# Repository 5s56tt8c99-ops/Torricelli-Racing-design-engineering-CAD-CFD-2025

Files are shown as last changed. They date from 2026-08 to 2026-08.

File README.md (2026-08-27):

# Torricelli-Racing-design-engineering-CAD-CFD-
This project shows the creation and CFD analysis of a formula 1 in schools car that took part at the triveneto regional finals of 2025.
The triveneto stage was a second event we took place after passing the preliminary stage. Here I show the differences between the two cars and the file of the second and more competitive one. The software used are Autodesk CFD and Autodesk Fusion.

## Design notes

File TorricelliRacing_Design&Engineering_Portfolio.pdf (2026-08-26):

# tORRICELLI

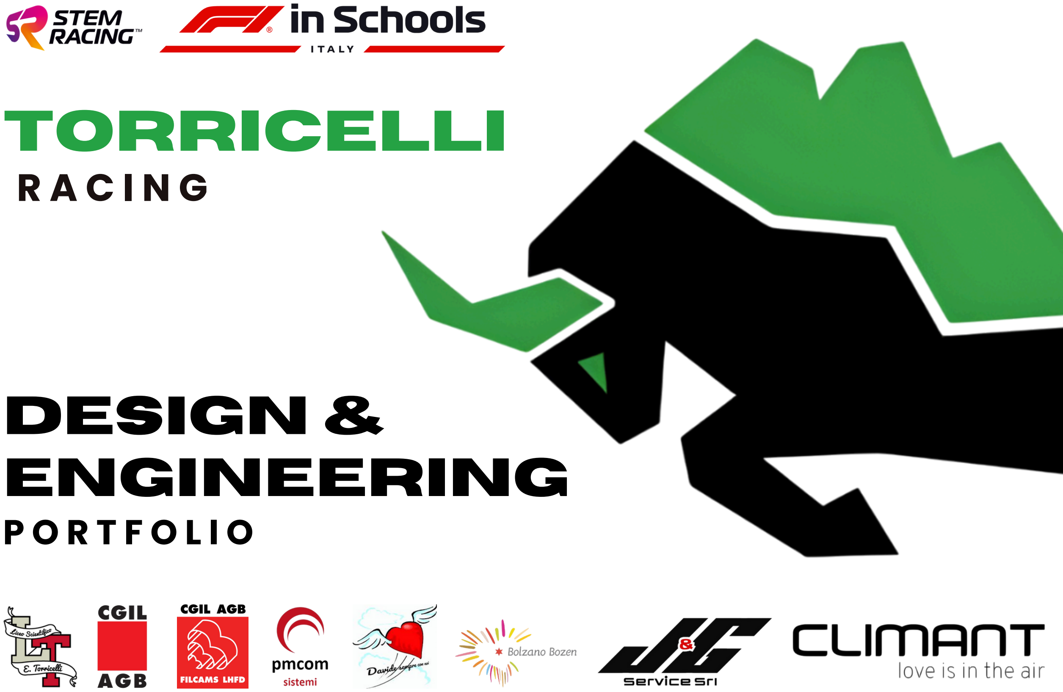
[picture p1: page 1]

# engineering

# P O R T F O L I O

# design &

# R A C I N G

# QUALIFIERS’ CAR ANALYSIS

After completing the regional qualifiers, we carefully analyzed the performance of our car. Although it showcased some good aerodynamic ideas — like airfoil-shaped wings and airflow management devices — several weaknesses were identified, highlighting the need for a major redesign.

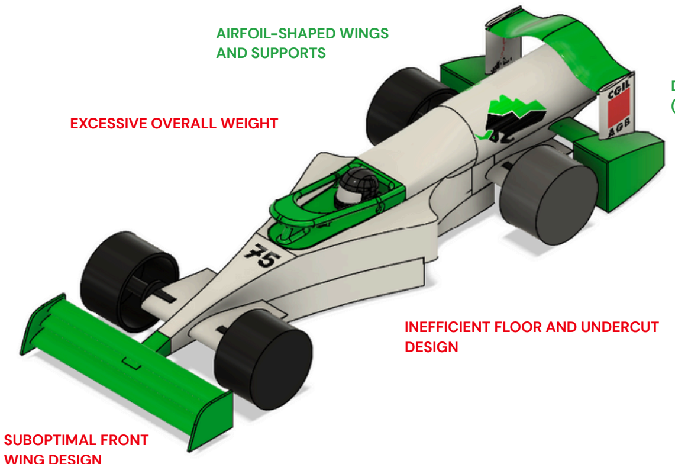
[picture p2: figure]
AIRFOIL-SHAPED WINGS AND SUPPORTS; SUBOPTIMAL FRONT; EXCESSIVE OVERALL WEIGHT; INEFFICIENT FLOOR AND UNDERCUT DESIGN

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
# MAIN GOALS

Based on this analysis, we decided to completely redesign the car while retaining some successful concepts. Our main goals were:
Reducing the weight down to the minimum limit by redimensioning some shapes (like minimizing the length of the chamber) and changing materials to some better performant ones
Redesigning the front wing for improved airflow management and reduced drag and removing unneccessary parts
Optimizing the floor and undercut for a cleaner and faster air passage
Introducing bearing-based wheel assemblies to minimize friction and rotational resistance
The regulatory updates allowed us to innovate further, particularly in the wheel and support structure design, pushing us to rethink every element with performance optimization in mind.

DECENT AERODYNAMIC CONCEPTS (E.G., AIRFLOW CLEANERS)

WING DESIGN

## QUALIFIERS’ CAR

## REGIONAL FINALS’ CAR

VS

EXPLANATION: STRENGTHS / WEAKNESSES

# KEY DESIGN OBJECTIVES

At the start of the redesign phase, we set two main design priorities: maximizing underbody airflow (big undercut) and minimizing the car’s frontal surface area (narrow wheel axis width). These choices aimed to reduce aerodynamic drag while maintaining stability and regulatory compliance.

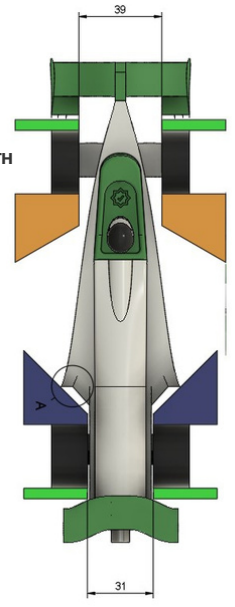
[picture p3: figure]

Key Objectives
Big undercut: create the largest possible free airflow path under the car to reduce ground friction and air turbulence and maximise free flow.
Minimal width: design a narrow wheel axis width and small wheels to lower drag and minimize frontal area.
New front wing: redirect airflow efficiently around the front wheels without blocking the underbody airflow.
Lightweight components: replace or redesign heavy parts to achieve minimum weight.
Simple and small rear wing: keep the rear wing lightweight and aerodynamically clean to avoid unnecessary drag

# SKETCHING PHASE

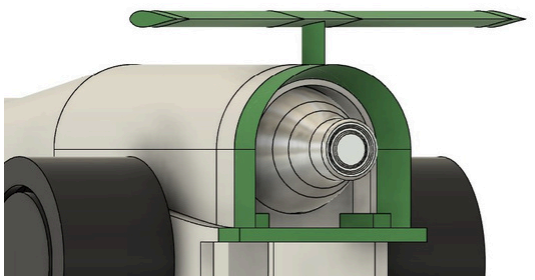
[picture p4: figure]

In the early sketching stage, we explored two possible layouts for the Virtual Cargo (mandatory volume):
Virtual Cargo placed under the Halo
Virtual Cargo placed behind the Halo
We chose the second option as it allowed a higher and more continuous undercut, better supporting our key aerodynamic concept.
Further design decisions — such as the placement of sidepods, deflectors and halo connections — were all influenced by our goal to maintain a clean, unrestricted airflow underneath the car.

MINIMAL WIDTH

SMALL AND SIMPLE REAR WING

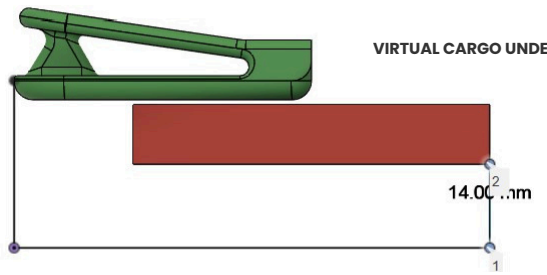
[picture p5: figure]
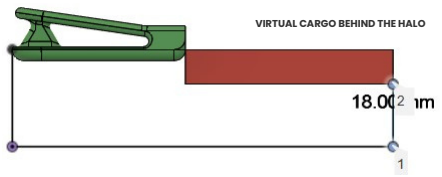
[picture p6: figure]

VIRTUAL CARGO BEHIND THE HALO | VIRTUAL CARGO UNDER THE HALO

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
Redesign Motivation
The front wing used in the qualifiers was aerodynamically inefficient and heavy. To improve performance, we chose to completely redesign the wing, focusing on drag reduction, regulatory compliance and structural simplicity.

Design Choices and Features
A single-vane wing was selected for simplicity and reduced frontal impact with air.
It is attached to a short, thin nose cone, minimizing drag and maximizing clean airflow.
Endplates were placed in front of the wheels, designed to redirect air both around and over them, while complying with rule T8.7.
The first version of the endplates was too heavy and forced an excessively narrow wing. We redesigned them to be slimmer and more effective.
The wing is mounted high above the ground to eliminate the need for extra connectors (which would increase drag) and is slightly bent downwards to meet rule T8.5.2.
A neutral airfoil shape was used, avoiding both lift and downforce to maintain clean airflow.

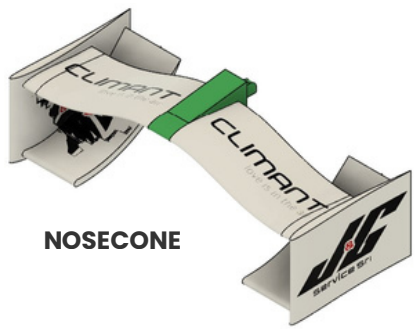
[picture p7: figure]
NOSECONE

Manufacturing and Assembly
The entire wing and nose assembly is printed as a single piece, ensuring precision and reducing weight. A custom mounting point was designed to connect the front wing directly to the car body, offering rigidity with minimal aerodynamic disruption.

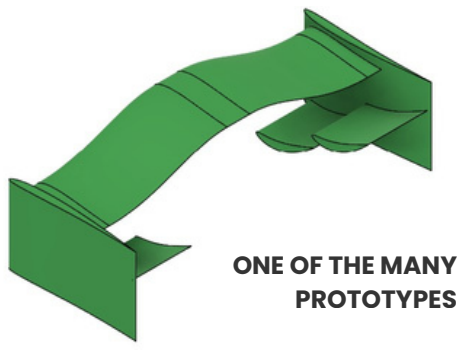
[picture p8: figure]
ONE OF THE MANY PROTOTYPES

Performance Improvement
Compared to the first version, our final design showed a 19% reduction in drag based on CFD analysis — confirming the aerodynamic benefits of our approach.

# FRONT WING & SUPPORT DEVELOPMENT

To address the aerodynamic issues of the initial designs, we tested over ten different front wing specifications — many with small adjustments, but a few with major conceptual changes.
We first modified the angle of the endplate’s airfoil, making it less steep. CFD results improved slightly, but the problem wasn’t fully solved.
Next, we tested a double-vane endplate, which reduced drag further, but still didn’t meet our expectations.
Finally, we created a more unconventional solution: we added cambered airfoils underneath the endplates to redirect air sideways. This approach showed a significant improvement in drag reduction and was integrated into the final design.
Each version was simulated using Autodesk CFD and evaluated with visual flow maps and pressure values.

# DEVELOPMENT ITERATIONS & CFD TESTING

FEATURE | FINAL DESIGN
WING TYPE | SINGLE VANE
AIRFOIL PROFILE | NEUTRAL
ENDPLATE POSITIONING | FRONT OF WHEELS
NOSE CONE | THIN AND SHORT
ASSEMBLY | PRINTED AS SINGLE BLOCK
DRAG REDUCTION (CFD) | ~19% VS. FIRST DESIGN
RULE COMPLIANCE | T8.5.2, T8.7

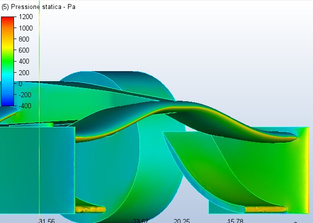
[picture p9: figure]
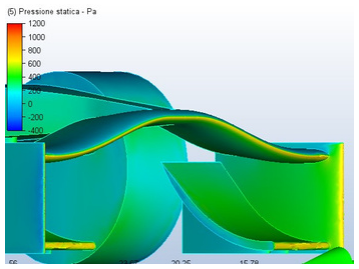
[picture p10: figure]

FIRST PROTOTYPE’S CFD | FINAL PROTOTYPE’S CFD

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
FEATURE | FINAL DESIGN
SUPPORT TYPE | ADD-ON WITH CENTER STRUT
CONNECTION POINT | REAR OF CHAMBER
ASSEMBLY COMPLEXITY | VERY LOW
DRAG IMPACT | SIGNIFICANTLY REDUCED

# REAR WING & MOUNTING SYSTEM

Redesign Motivation
The rear wing from the qualifiers was overly complex and difficult to assemble. Since the rear wing generates little aerodynamic benefit and primarily adds drag, our goal was to simplify it while maintaining stability and aesthetic integration.

Design Evolution
We removed the previous connection system, which attached the wing to rear deflectors, as it was unnecessarily complicated and tested two new mounting solutions:
a. A wing that twists and connects directly to the chamber walls.
A simplified add-on behind the chamber, with a small airfoil-shaped support connecting to the center of the wing.

b.

After comparison, we chose the second design due to its lower surface impact, improved stability, and ease of manufacturing.

Key Features
Compact and clean shape with minimal drag footprint.
Shortened rear section of the car to compensate for the longer wheelbase caused by halo and virtual cargo placement.
Final wing has a curved profile, which better integrates with the car’s structure and makes the wing be compliant with both rule T7.9 and T9.4.1

Outcome
The new rear wing is aerodynamically cleaner, structurally simpler, and much easier to mount — improving both performance and assembly workflow.

TWISTED WING

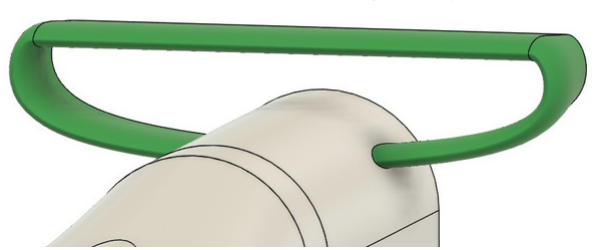
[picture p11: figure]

MOUNTED WING

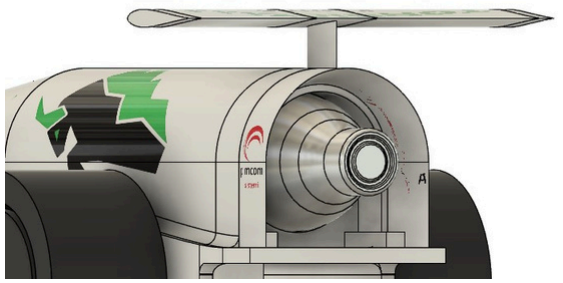
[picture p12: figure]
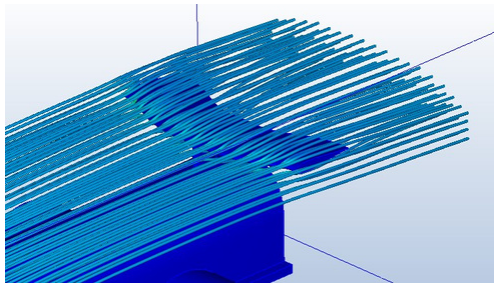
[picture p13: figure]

REAR WING CFD ANALYSIS: CLEAR FLOW WITHOUT | REAR VIEW OF THE REAR WING
TURBOLENCES

FEATURE | DESIGN CHOICE
VIRTUAL CARGO | BEHIND HALO
UNDERCUT SHAPE | CONTINUOUS, WIDE
TUNNEL WALLS | CONSTANT-WIDTH, STRAIGHT
SIDEPODS HEIGHT | 2 MM FROM GROUND
HALO-CHAMBER LINK | TOP: LOFTED / BOTTOM: VERTICAL

# DESIGN OBJECTIVES

One of the key goals in our redesign was to maximize free airflow beneath the car by creating a wide and straight undercut. At the same time, we aimed to minimize turbulence and ensure structural simplicity.

Element Positioning and Initial Decisions:
During the sketching phase, we compared two possible layouts for the Virtual Cargo: below or behind the Halo. We chose the second option as it allowed a taller and more continuous undercut, improving airflow performance while still complying with all regulations.

# UNDERCUT & TUNNEL DEVELOPMENT

The undercut area was redesigned to be wider and more stable than in the qualifiers’ car.
In the previous design, the use of deflectors under the car caused unwanted turbulence. We replaced them with tunnel walls that keep the airflow attached and laminar.
These walls maintain the same width for their entire length to avoid flow separation.
A simple vertical connection links the chamber to the tunnel roof, avoiding unnecessary curves and aiding clean flow.

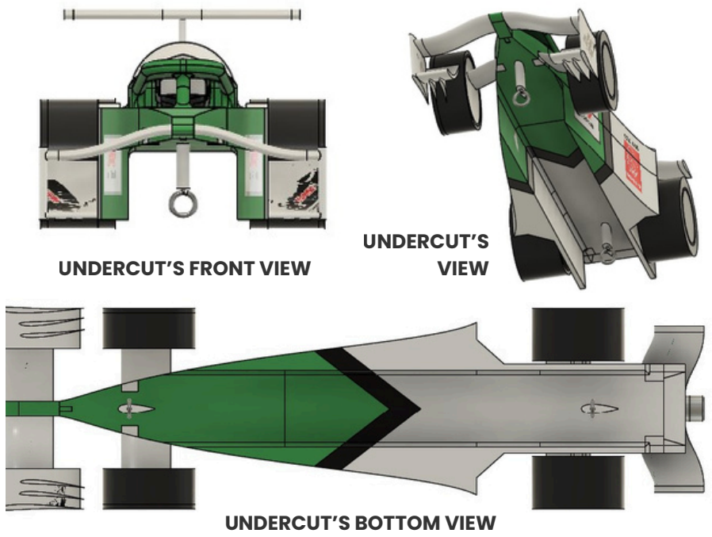
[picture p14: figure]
UNDERCUT’S BOTTOM VIEW; UNDERCUT’S FRONT VIEW; UNDERCUT’S VIEW

# SIDEPODS & HALO-CHAMBER CONNECTION

We added sidepods raised 2 mm off the ground to redirect air around the rear wheels.
The top of the Halo connects to the chamber with a clean lofted transition. A small cylindrical-shaped part was added to the loft in order to clean the turbolences generated by the helmet. The bottom half forms vertical walls connecting directly to the tunnel roof, simplifying geometry and aiding C

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
FINALS’ CAR’S UNDERCUT FLOW: THE FLOW IS STRAIGHT WITHOUT UNWANTED DEVIATIONS

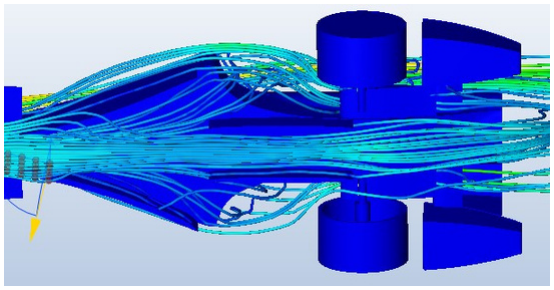
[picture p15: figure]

QUALIFICATIONS’ CAR’S UNDERCUT FLOW: PART OF THE FLOW IS DIVERTED LATERALLY (COANDA EFFECT & VENTURI EFFECT) WHICH

SIDEPOD & HALO-CHAMBER CONNECTION GENERATES UNWANTED TURBOLENCE

W

H

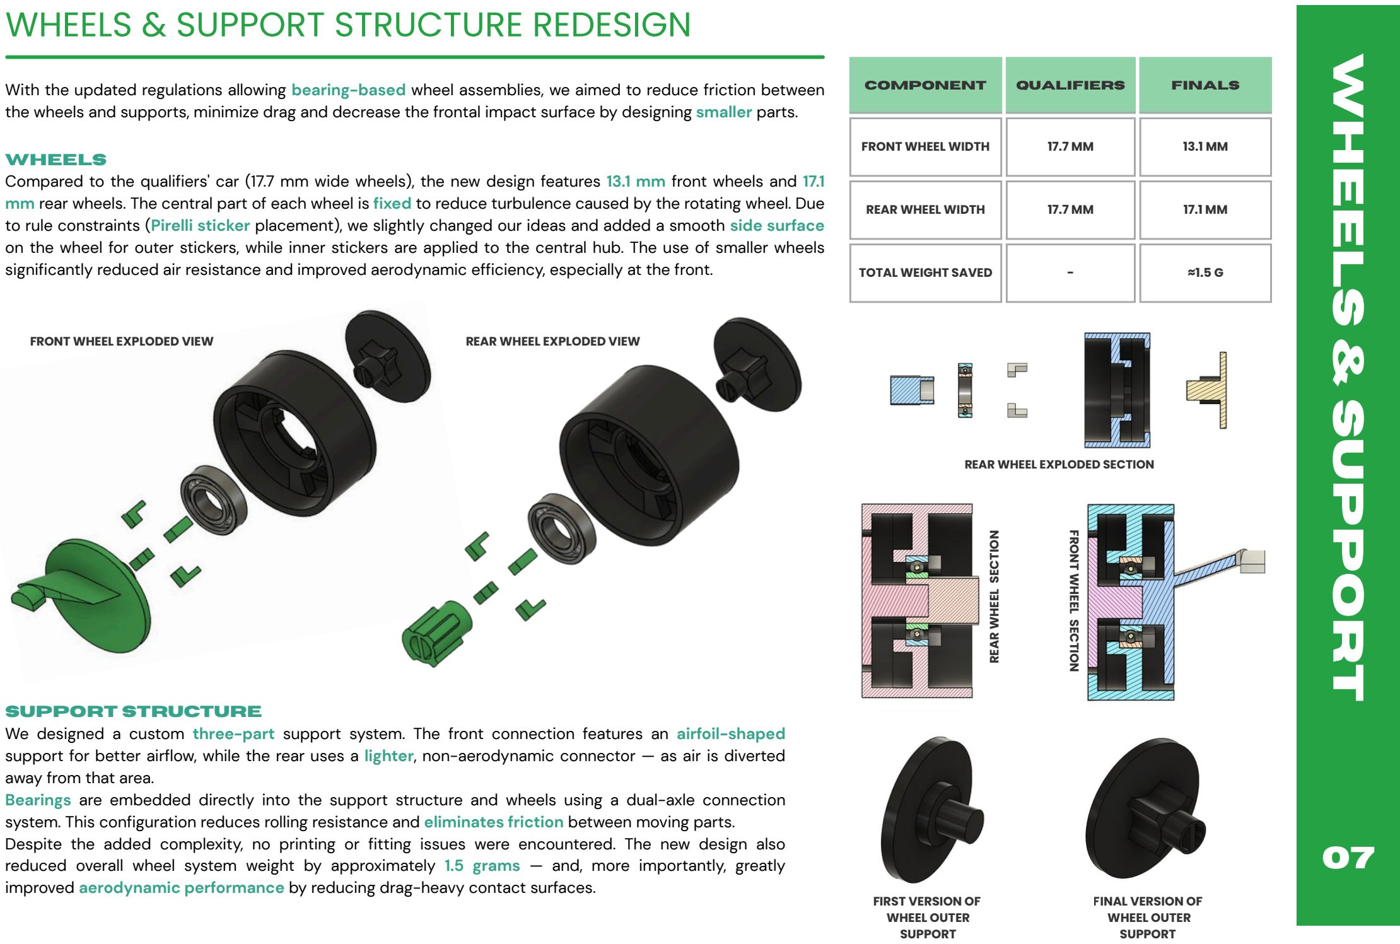
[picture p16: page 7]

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
# THE TEAM WHEELS & SUPPORT 07

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
# SIG

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
allo

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
el a

s

s

e

m

blie

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
minimiz

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
al im

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
alle

r
p

a

r

t

s. Wheels Compared to the qualifiers' car (17.7 mm wide wheels), the new design features 13.1 mm front wheels and

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
els. T

h

e

c

e

n

t

r

al p

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
el is

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
el. D

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
elli

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
slig

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
r id

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
el f

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
hile in

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
plie

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
al h

u

b. T

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
alle

r

w

h

e

els
sig

nific

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
d im

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
ficie

n

c

y,

e

s

p

e

cially

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
t. Support Structure We designed a custom three-part support system. The front connection features an airfoil-

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
hile

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
a li

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
air is

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
a. Bearings are embed
d

e

d

dir

e

c

tly in

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
m. T

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
ollin

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
s. Despite the added complexity, no printing or fitting issues were encountered. The new desig n

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
all w

h

e

el s

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
e im

p

o

r

t

a

n

tly,

g

r

e

a

tly improved aerodynamic performance by reducing drag-heavy contact surfaces. FRONT WHEEL EXPLODED VIEW | REAR WHEEL EXPLODED VIEW | REAR WHEEL EXPLODED SECTION REAR WHEEL SECTION | FRONT WHEEL SECTION

# WEIGHT REDUCTION STRATEGY & FINAL MASS

Initial Challenge
Our first complete design was over 10 grams above the weight limit (qualifiers car: ~95g without CO₂ canister).
Since the F1 in Schools block has low density, we realized that major reductions had to come from 3D-printed components. The bearings (8g total) were non-negotiable, wings were already small, so we could mostly trim the wheels.

Reduction Process
Switched from PLA to Polypropylene (PP) for some components (1.25g/cm³ vs. 0.9g/cm³).
Reduced wheel surface thickness from 2 mm to 1.5 mm.
Replaced the inner connection with a lighter rim-style structure.
Cut excess material from supports and bearing holders using structural optimization.
In order not to increase the weight of the car and for reasons of time, we decided not to paint the car. We put on the stickers: name, logo, number and sponsors (plus the pirelli and f1 stickers in schools that will be given at the regional finals)

FinalWeight Estimate
After design optimization and printing tests, the estimated final mass is ≈50.2g (without stickers).
This is almost 45g lighter than the qualifiers car and just above the minimum allowed.

Performance Rationale
Based on our data from qualifiers, 10g of excess weight cost us approximately 0.1 seconds in race time — making this weight reduction crucial for improving our performance.

HEAVIER WEIGHT

REDUCED WEIGHT

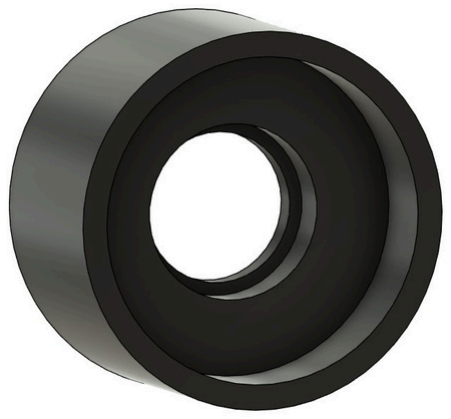
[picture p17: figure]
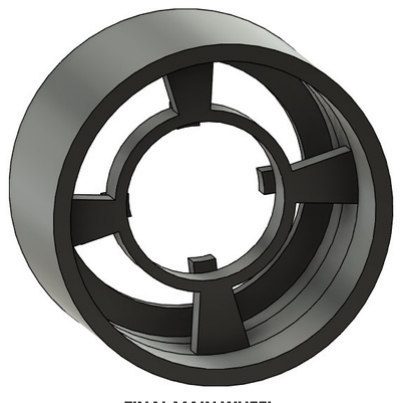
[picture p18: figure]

FIRST DESIGN OF MAIN WHEEL | FIRST WEIGHT REDUCTION | FINAL MAIN WHEEL

WEIGHT REDUCTION:
~3.4G FOR EACH WHEEL (FROM 7G TO 3.6G) AND ~44.84G FOR THE FULL CAR - W/O CAN - (FROM 95G TO 50.16G)

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
# SIS

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
# E IM

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
D. W

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
cially

o

n
vis

u

alizin

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
d id

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
e. More than 10 versions of the front wing alone were tested, together with diff e

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
el w

alls

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
, in

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
ximis

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
e. Key Findings The final front wing reduced drag by ~19% compared to the initial ve

r

sio

n. Positioning the Virtual Cargo behind the Halo significantly improved the u n

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
w. Removing underbody deflectors and replacing them with clean tunnel walls elimina t

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
d in

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
r. CFD Tools Used Traces to observe direction and velocity

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
r in

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
all c

alc

ula

tio

n

s

t

o id

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
al a

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
al q

u

alifie

r

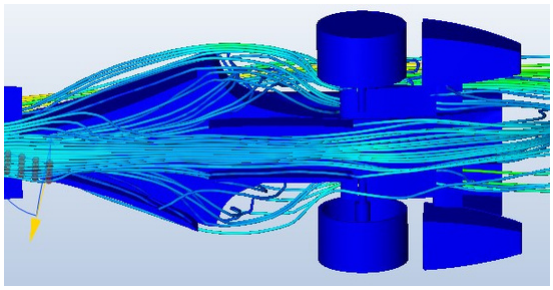
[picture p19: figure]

s' car, with major gains in drag reduction and flow cleanliness. | FINALS’ CAR’S UNDERCUT FLOW:

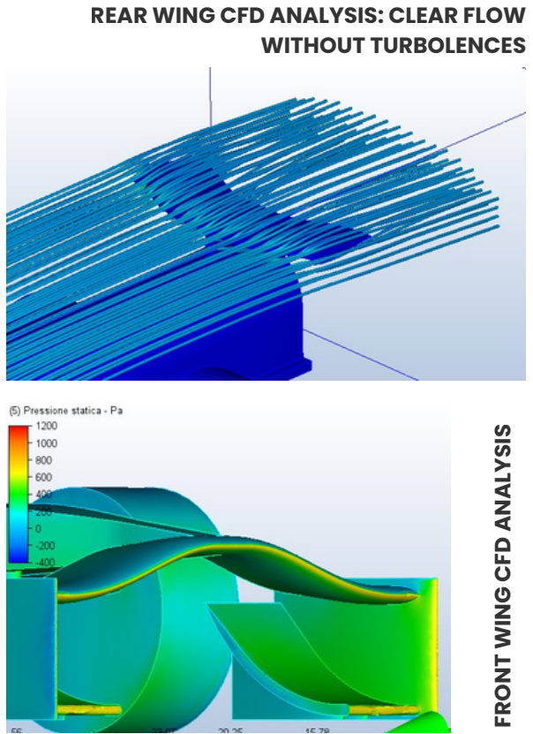
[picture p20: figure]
FRONT WING CFD ANALYSIS RE

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
FINALS’ CAR’S FRONT FLOW QU

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
# THE TEAM CFD & IMPOVEMENTS 09

# MATERIALS AND 3D PRINTING STRATEGY

Material Selection
To reduce weight and maintain structural reliability, we carefully selected materials for each printed component:
PLA (d=1.25 g/cm³) was used for the front and rear wings and for the internal supports, due to its rigidity and easier printing with support materials.
Polypropylene (PP) (d=0.9 g/cm³) was chosen for the remaining components because of its lower density.
However, PP is more flexible and difficult to print accurately. Some parts showed small surface irregularities, which we managed by simplifying geometries and avoiding too-thin features.

Printing Process
All parts were printed using FDM 3D printers, at BITZ FabLab (unibz): we used a Ultimaker S3 dual extrusion and a Prusa XL
Water-soluble support structures were used with PLA prints to allow more complex shapes and cleaner results.
Each component was printed at least once for testing before final assembly. As of April 29, most parts had already been approved, except for the rear wheels.

Design Adjustments
During printing trials, we noticed slight underweight values in some components, especially those in PP. To reach the desired final weight (target: ~50g), we reprinted the wings and supports in PLA, slightly heavier and more rigid.
These adjustments helped balance aerodynamic efficiency, weight constraints and printability.

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
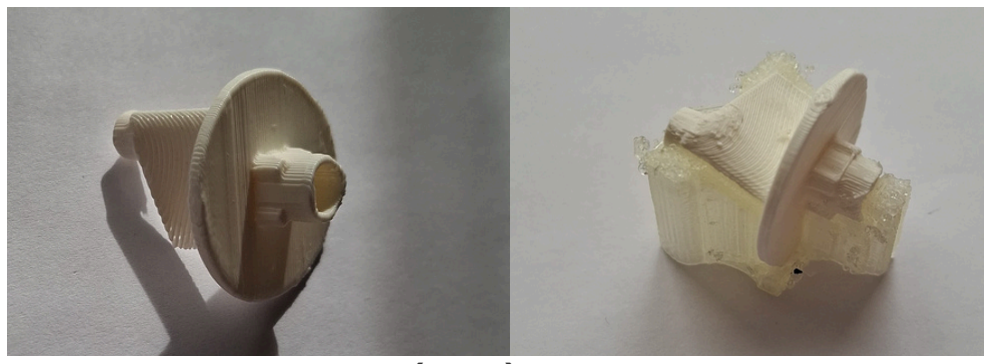
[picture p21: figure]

FRONT WHEEL INNER SUPPORT (IN PLA) PRINTED WITH WATER-SOLUBLE SUPPORTS

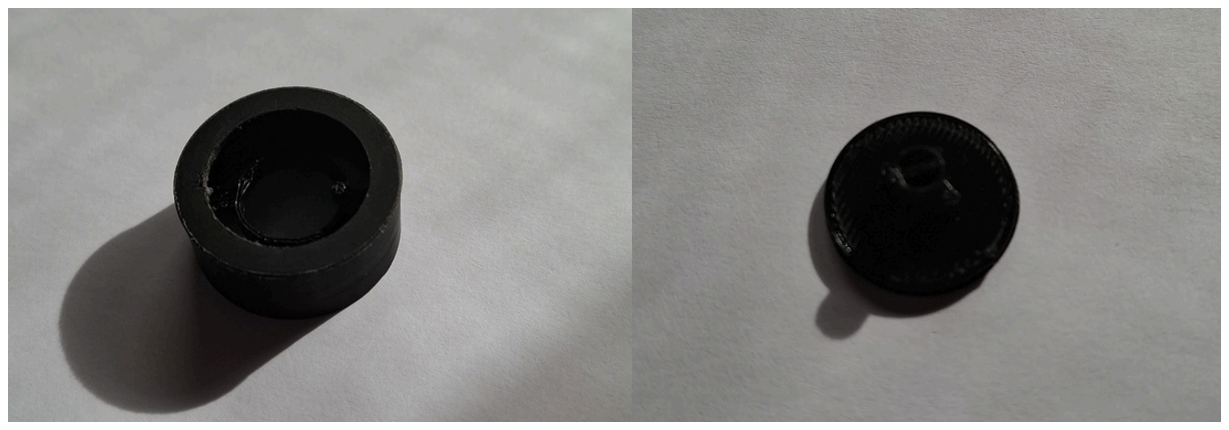
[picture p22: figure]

WHEEL AND WEEHL OUTER SUPPORT IN BLACK PP

FRONT WHEELAND REAR WING (IN WHITE PLA)

COMPONENT | MATERIAL | REASON
FRONT & REAR WINGS | PLA

RIGIDITY AND
PRINT PRECISION
INTERNAL SUPPORTS | PLA

SLIGHTLY HEAVIER,
MORE STABLE
ALL OTHER PARTS | PP

LIGHTWEIGHT,
ACCEPTABLE FLEXIBILITY

THE 3D PRINTERS THAT WE USED

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
# RIN

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
divid

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
millin

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
). 3D
P

r

i

n

t

i

n

g: PLA and
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
e lo

c

al F

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
s. P

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
). All parts underwent print testing before approval. Milling (CNC): The body is milled from the official model block using

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
al p

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
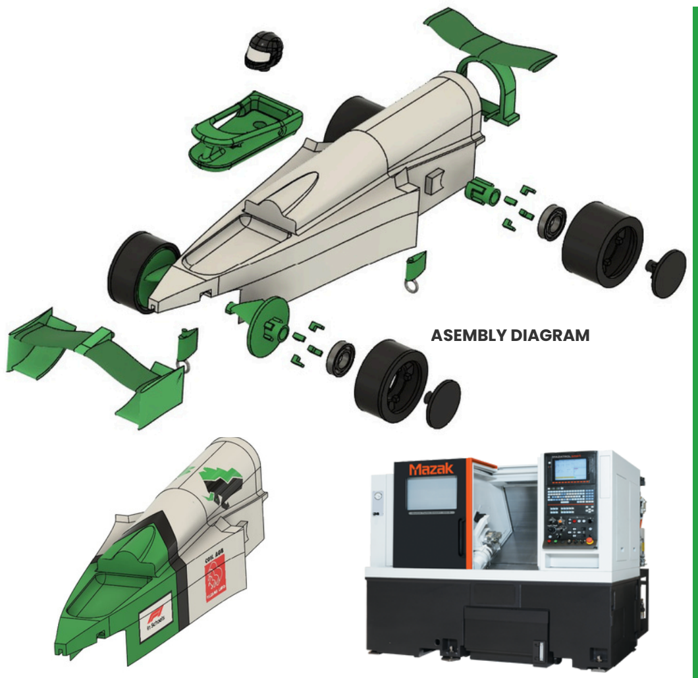
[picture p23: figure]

). Due to delays and technical limitations of local workshops, this task was concluded a bit late that expected. Assembly Approach Our car is designed to allow fast and stable assembly. The wings are printed in a single block and connect directly to the body using integrated slots or pegs. Bearings are inserted into wheel supports, then aligned with dual axle pins. Tolerances were verified during early print tests. Tools used: sandpaper, files, glue. This workflow helped us simplify logistics, reduce unexpected fitting problems and ensure that once the main chassis is milled, final assembly can be completed quickly and precisely. Testing and regulations compliance After printing each peace, we measured it to make sure it respected the regulation. We used: a digital scale to ensure the weights corresponded to the theoretical ones and that the car didn’t weight less than 50g a caliber to measure the lenghts and widths of diffrent parts little steel weights to test the halo’s resistance FINAL REFLECTIONS This project taught us how important it is to balance performance, precision and planning. Managing time and resources was challenging and real progress only came when ideas turned into concrete action. The experience helped us grow as a team and showed us how rewarding it is to see a design evolve from sketch to real car. If we had to start over, we would take faster decisions, communicate more clearly and leave more time for testing and refinement. | THE TEAM FINISHING 11

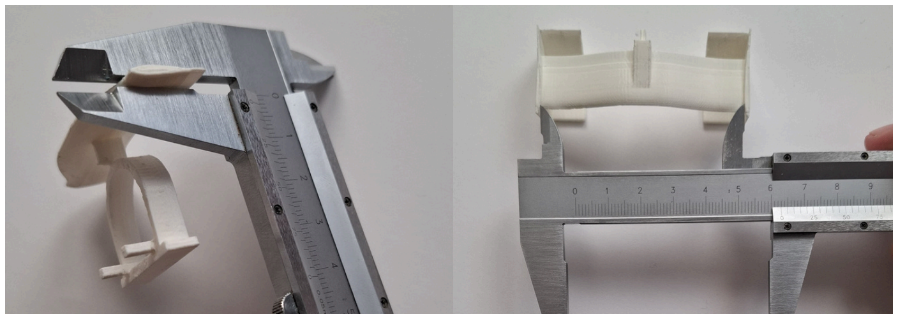
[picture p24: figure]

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
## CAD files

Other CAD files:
TorricelliRacing Preliminary phase 2025.f3d
TorricelliRacing_1_FullCar_3DModel 2025.f3d
